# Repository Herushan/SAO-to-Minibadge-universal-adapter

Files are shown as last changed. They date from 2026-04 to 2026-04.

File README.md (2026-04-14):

# SAO-to-Minibadge-universal-adapter
This is a minibadge format adapter that can be soldered for SAO to Minibadge or Minibadge to SAO usage. This will allow Minibadges to be used on DEFCON badges or SAOs used on Minibadge displays/badges.

All the PCB KiCad files are provided with the gerber zip so you can just buy the boards with that.

Parts are simple with just 16 male header pins or 2 female single row 8 hole adapter and then either a male or female SAO adapter depending on which way you are going. See video below for details. Images of completedd boards and boards back and front.





The video on how to solder and make this adapter is here:
https://youtu.be/1QgKpa0yQGg

Still figuring out the best license for this but for personal use and please do not sell this item.

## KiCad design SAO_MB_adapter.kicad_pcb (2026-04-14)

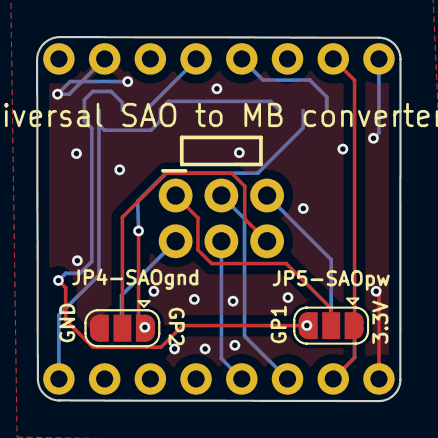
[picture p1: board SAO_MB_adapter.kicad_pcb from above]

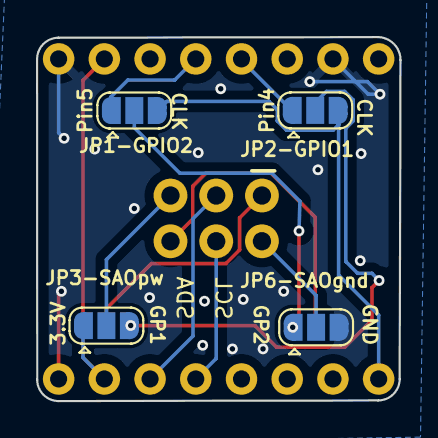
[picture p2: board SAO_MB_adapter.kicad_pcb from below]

Board: 2 copper layers, 20.2 x 20.2 mm, 8 parts (4 on the bottom side), 13 nets.

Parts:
J1: CONN_03X2FEMALE; 2X3-SHROUDED
JP1-GPIO2, JP2-GPIO1, JP3-SAOpw, JP4-SAOgnd, JP5-SAOpw, JP6-SAOgnd: SolderJumper_3_Open; SolderJumper-3_P1.3mm_Open_RoundedPad1.0x1.5mm
MB1: MiniBadge_Full

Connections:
+3.3V: JP3-SAOpw.1 (A), JP5-SAOpw.1 (A), MB1.7 (+3V3), MB1.15 (3V3+)
CLK: JP1-GPIO2.3 (B), JP2-GPIO1.3 (B), MB1.9 (CLK)
GND: JP4-SAOgnd.3 (B), JP6-SAOgnd.3 (B), MB1.2 (GND), MB1.8 (GND), MB1.16 (GND)
GPIO1: JP2-GPIO1.2 (C), JP3-SAOpw.3 (B), JP5-SAOpw.3 (B)
GPIO2: JP1-GPIO2.2 (C), JP4-SAOgnd.1 (A), JP6-SAOgnd.1 (A)
Prog/MISO: JP1-GPIO2.1 (A), MB1.5 (PROG3)
Prog/MOSI: JP2-GPIO1.1 (A), MB1.4 (PROG2)
SAO_1: J1.1, JP3-SAOpw.2 (C)
SAO_2: J1.2, JP4-SAOgnd.2 (C)
SAO_3: J1.5, JP5-SAOpw.2 (C)
SAO_4: J1.6, JP6-SAOgnd.2 (C)
SCL: J1.4, MB1.13 (SCL)
SDA: J1.3, MB1.14 (SDA)
